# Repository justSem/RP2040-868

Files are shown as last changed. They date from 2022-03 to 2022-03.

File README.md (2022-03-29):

> `BE AWARE` This project is still in active development, I'm still in the process of ordering and testing prototypes, so the latest version is not tested to be fully-working as of yet.

# RP2040-868
A GPRS/GNSS/BTLE and LiPo/Li-ion charger integrated Pi Pico on credit-card format.

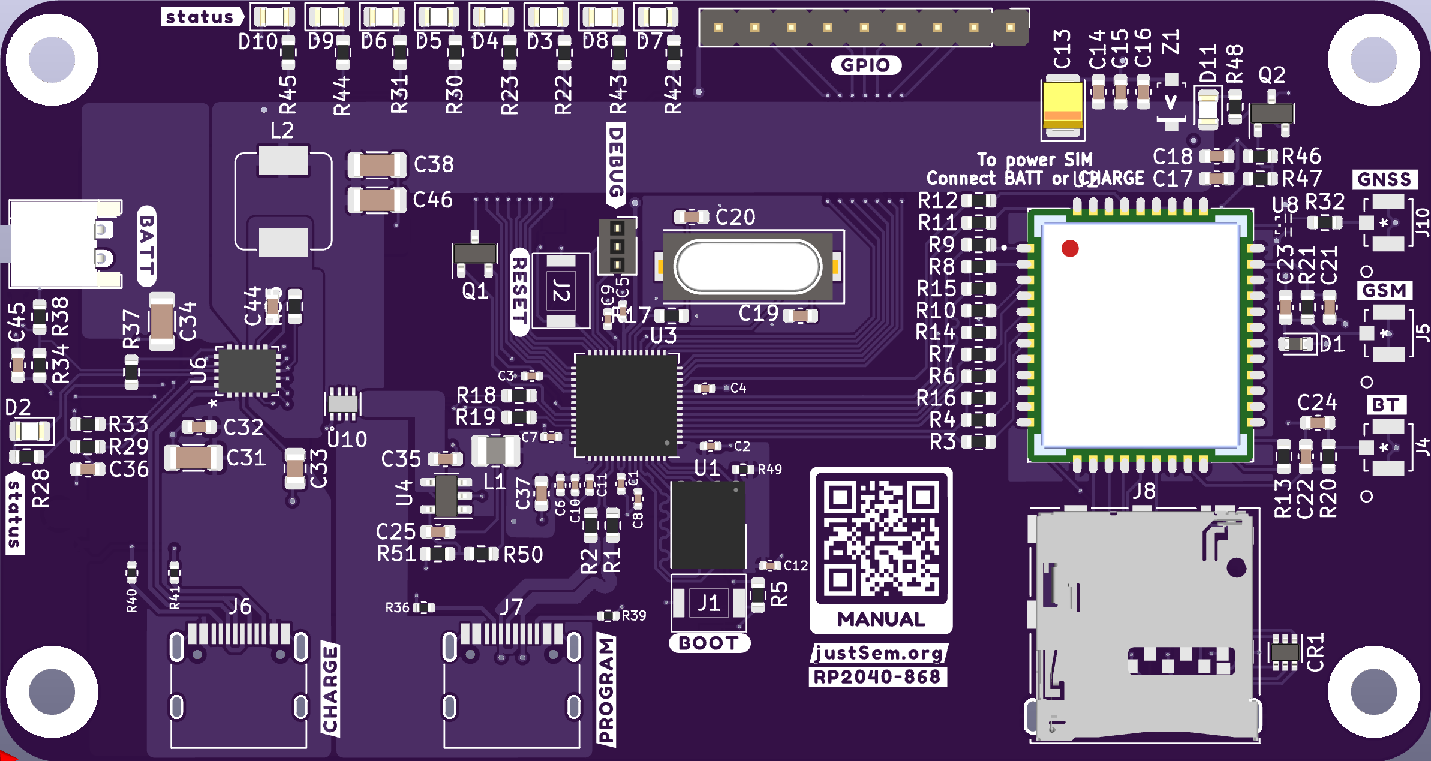
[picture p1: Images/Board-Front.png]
Board Front

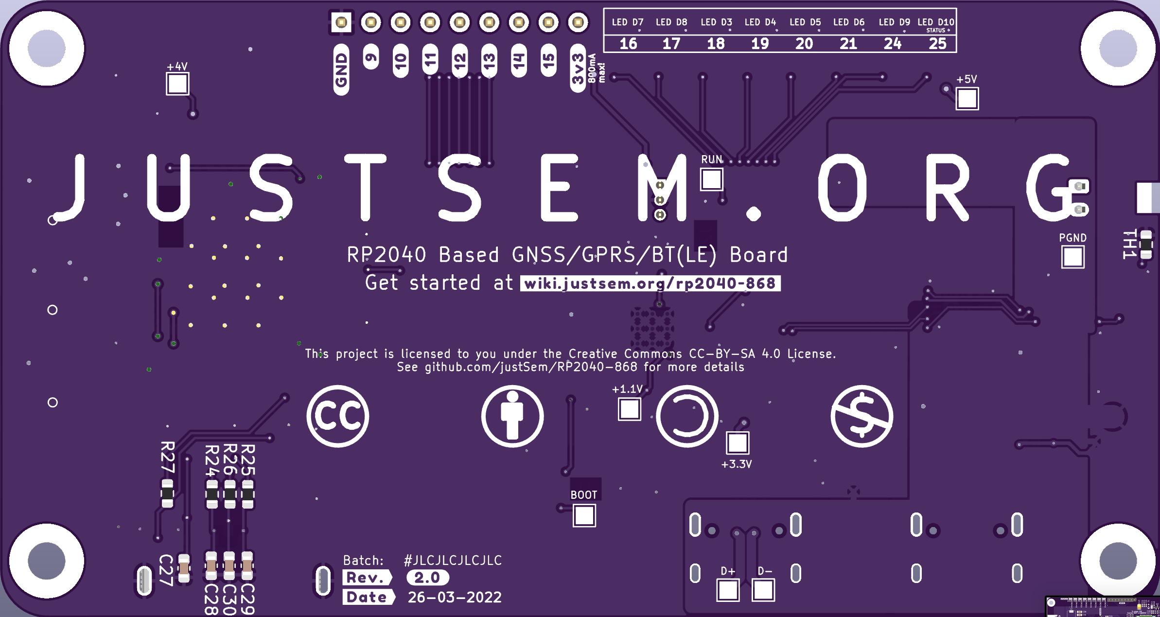
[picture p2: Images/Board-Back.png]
Board Rear

_Size: 99x50mm_

Title says it all!

This is a fully integrated RP2040-based board featuring the following:

* GPRS Enabled (with microSIM card format)
* GNSS (GPS, GLONASS, BEIDOU)
* BT(LE)
* Integrated LiPo/Li-ion charging circuit.
* USB-C (in USB2.0 mode) ports for future proofing.
* Programmable as if it's a "normal" RPI Pico
* Auto-switching power source: In case you connect both the Battery/USB Power and the USB-Program port, the device will automatically switch it's power source to the "PROG" port.

## The boards origin
Me and my friends work with GPS trackers a lot, for various purposes. For a while we used cheap AliExpress trackers, but we felt they couldn't be fully trusted. They're dirt-cheap but in return, closed-source.
We had absolutely no guarantee that it won't secretly send our data back to China.
So I decided to make our own version.

What started as a simple board grew out to be a fully-programmable board.
Since most of our group favor Python over C++ (simply because we're more used to Python :) ) we went with an RP2040

## Board Details
* The charger is a Monolithic Power [MP2624](https://www.monolithicpower.com/en/mp2624.html) 
* The GPRS/GNSS/BT(LE) Module is a SIMCom [SIM868](https://datasheet.lcsc.com/lcsc/1811011410_SIMCom-Wireless-Solutions-SIM868_C89549.pdf)
* At the heart of the board you'll find a Raspberry Pi [RP2040](https://datasheets.raspberrypi.com/rp2040/rp2040-datasheet.pdf)

## Quick Start
If you have the board you can simply access the programming mode by going through the following steps:
1. Connect a USB-C cable to the port labeled `PROG`
2. Press and hold the `RESET` button
3. Pres and hold the `PROG` button
4. Release the `RESET` button
5. Release the `PROG` button

The device should now present itself as removable storage to your system, allowing you to upload/download files to/from it.
You can use the provided code for some working examples.

## Costs
I haven't exactly calculated the costs. But for the 5 prototypes I built I spent roughly 30 euro's/board.
This includes overhead as some components had a minimium buy of 100 pieces.
So the exact costs are most likely below the number mentioned above.

# Planned Future
The plan is to make some changes in the future, these changes could be:

__Move to another Cellular Chip__

The SimCom chips can have 2A peak currents, which require a pcb designed to accomodate said currents.

__Support for more modern cellular acces__

GPRS is soon to be EOL. But at the time of writing there are no subsitutes which are worth the price in this project.
3G chips are available, but those networks are to be turned off 03-2022 in this country, which makes them not suitable for this project.
LTE-M (or other IoT bands) are still only available to commercial customers, chips for these networks are readily available but sadly not usable in this country.

For now it's waiting to see if any decent substitute will become available in the upcoming months.

__Support NanoSIM__

While it's theoretically possible with Rev 1.1 of the board, it hasn't been tested as of yet.

# F.A.Q.

__Do you sell these boards?__

No. I have no commercial interest with this project, but I might have spares at times, which I might be willing to send as long as you cover the costs.
Feel free to reach out if you're interested.

__Can you implement feature X?__

You're free to implement any software feature yourself. The boards are programmable for a reason :)

The board files can be altered using KiCad, enabling you to make hardware changes as well.

__I found a flaw__

Great! Please open an [issue](/issues/new/choose) and describe what you found.

# DISCLAIMER
I am in no way a professional PCB designer - this design could be flawed without me being aware of it.
I make things as a hobby without any guarantee on functionality, compatibility or reliability.
As stated in the [License](LICENSE.md) this product comes without any guarantee.

# CHANGELOG
### Rev 3.1
* Reversed change in crystal due to availability issues.
* Swapped SOIC-8 Flash for WSON variant.
* Removed SIM from `PROG` power-stage - no suitable DC-DC converter available for a reasonable price to do 5V->4V @ 2A.
* In order to access the SIM868 whilst programming, it is now required to either connect a battery, or an USB-cable to the `CHARGE` power-stage.

### Rev 2.0
* Swapped 100nF caps for 0402 to get them closer to the MCU.
* Moved around power-stage parts for thermal performance.
* Re-implemented USB connections to comply with USB Spec (impedance issues).

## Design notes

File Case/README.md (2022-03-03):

# RP2040-868 Case

__Revision:__ 1.0-TESTING

__CAUTION__: This is a _testing_ release. The case itself is still underway from the manufacturer - but it __should__ fit.

This 3d-printable case perfectly fits your board, and is additionally capable of holding a Triple-18650 Battery Pack. - I used [this](https://www.adafruit.com/product/5035) one as an example.

## On assembly

The screwholes on the side are made for standard M3 screws.
The holding pins in the bottom of the case are meant to hold M3 threaded inserts.

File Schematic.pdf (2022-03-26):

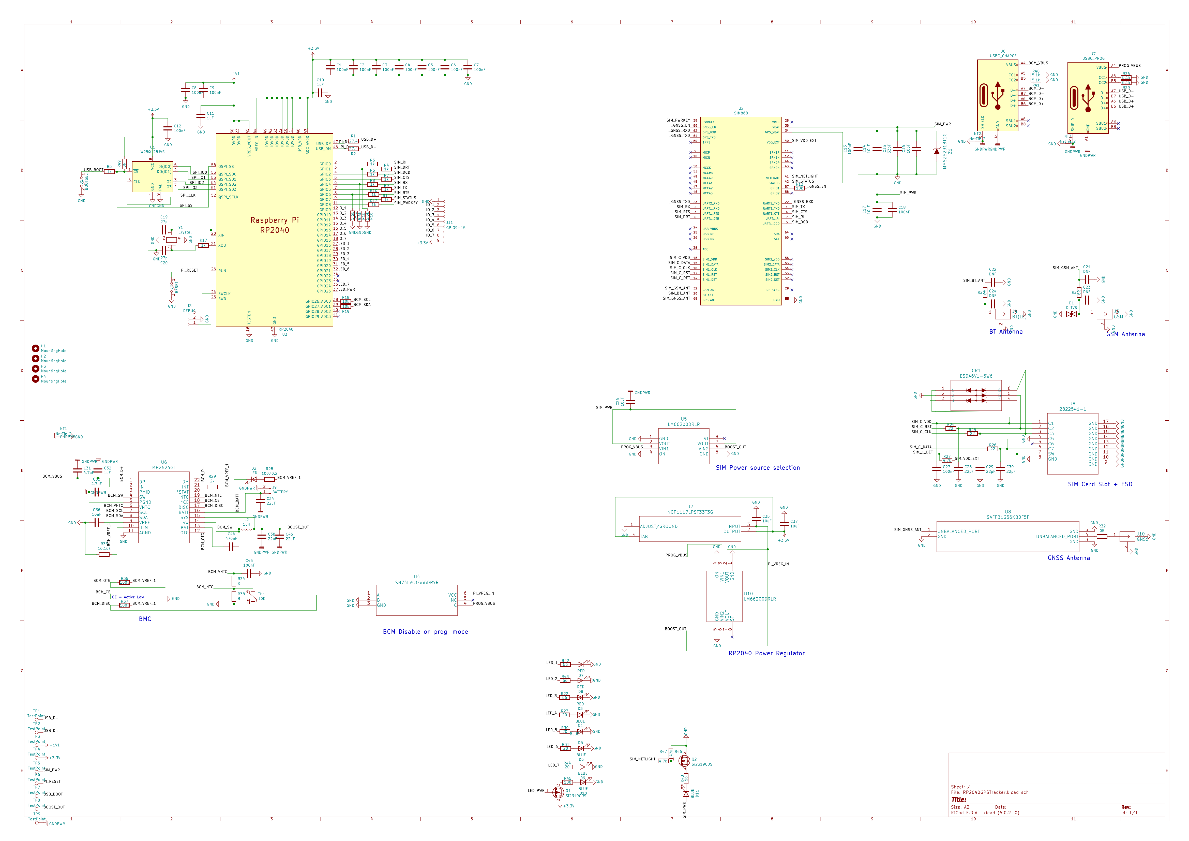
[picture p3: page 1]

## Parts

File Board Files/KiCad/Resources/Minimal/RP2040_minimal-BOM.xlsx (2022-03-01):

RP2040_minimal_r1 BOM
Item | Quantity | Reference | Part | Voltage | Current | Power | Material | Size | Tolerance | Manufacturer | Manuf. Part # | Description | Notes
1 | 3 | C1,C4,C17 | 10u | 16V |  |  | X5R | 0805_2012Metric | 10% | Murata | GRM21BR61C106KE15K | CAP CER 10UF 16V X5R 0805 | Or equivalent
2 | 2 | C2, C3 | 27p | 50V |  |  | C0G | 0402_1005Metric | 5% | Murata | GCM1555C1H270JA16D | CAP CER 27PF 50V C0G/NP0 0402 | Or equivalent
3 | 10 | C5, C6, C7, C9, C11, C12, C13, C14, C15, C16 | 100n | 25V |  |  | X7R | 0402_1005Metric | 10% | Murata | GRM155R71E104KE14J | CAP CER 0.1UF 25V X7R 0402 | Or equivalent
4 | 2 | C8, C10 | 1u | 10V |  |  | X6S | 0402_1005Metric | 10% | Murata | GRM155C81A105KA12D | CAP CER 1UF 10V X6S 0402 | Or equivalent
5 | 1 | J1 | USB_B_Micro |  |  |  |  |  |  | Amphenol | 10103594-0001LF | CONN RCPT USB2.0 MICRO B SMD R/A | Or equivalent
6 | 1 | J2 | 1x2 way header |  |  |  |  |  |  | Samtec | TSW-102-23-T-S | 2.54mm pin header 1x2 | Or equivalent
7 | 2 | J3, J4 | 2x18 way header |  |  |  |  |  |  | Samtec | TSW-118-23-T-D | 2.54mm pin header 2x18 | Or equivalent
8 | 2 | R1, R5 | 1k |  |  | 63mW |  | 0402_1005Metric | 1% | Yageo | RC0402FR-071KP | RES SMD 1K OHM 1% 1/16W 0402 | Or equivalent
9 | 1 | R2 | DNF |  |  |  |  | 0402_1005Metric |  |  |  |  | Do Not Fit
10 | 2 | R3, R4 | 27.4 |  |  | 63mW |  | 0402_1005Metric | 1% | Yageo | RC0402FR-0727R4L | RES SMD 27.4 OHM 1% 1/16W 0402 | Or equivalent
11 | 1 | U1 | NCP1117-3.3 |  |  |  |  | SOT-223-3 |  | ON Semiconductor | NCP1117ST33T3G | IC REG LINEAR 3.3V 1A SOT223
12 | 1 | U2 | W25Q128JVS |  |  |  |  | SOIC-8 |  | Winbond | W25Q128JVSIQ TR | IC FLASH 128M SPI 133MHZ 8SOIC
13 | 1 | U3 | RP2040 |  |  |  |  | QFN56 |  | Raspberry Pi | RP2040
14 | 1 | Y1 | ABLS-12.000MHZ-B4-T |  |  |  |  | HC49-US |  | Abracon | ABLS-12.000MHZ-B4-T | CRYSTAL 12.0000MHZ 18PF SMD

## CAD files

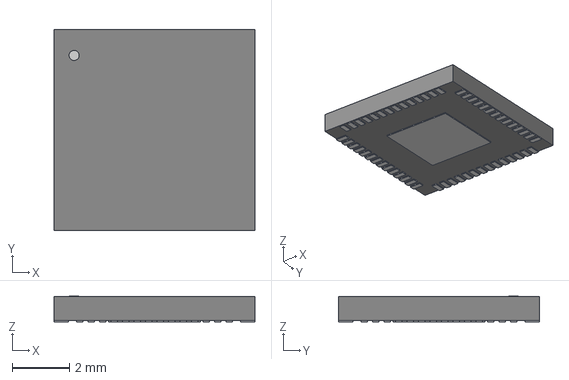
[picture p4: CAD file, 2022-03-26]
Board Files/KiCad/Resources/Minimal/QFN56_7X7_RPI.step
7.01 x 7.01 x 0.892 mm

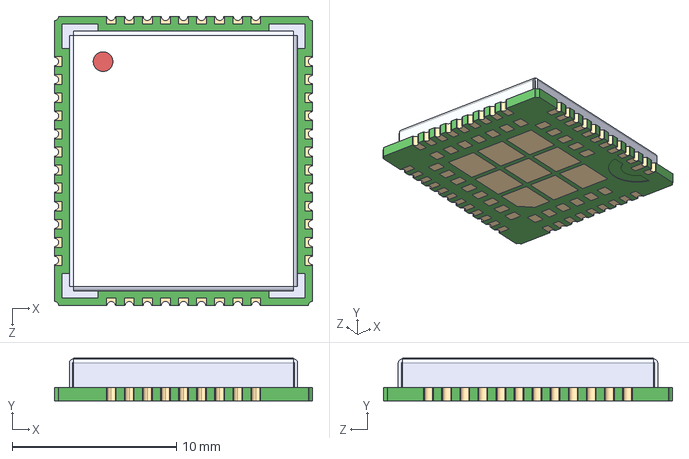
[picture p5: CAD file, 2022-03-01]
Board Files/KiCad/Resources/SIM868/SIM868.step
15.7 x 2.60 x 17.6 mm

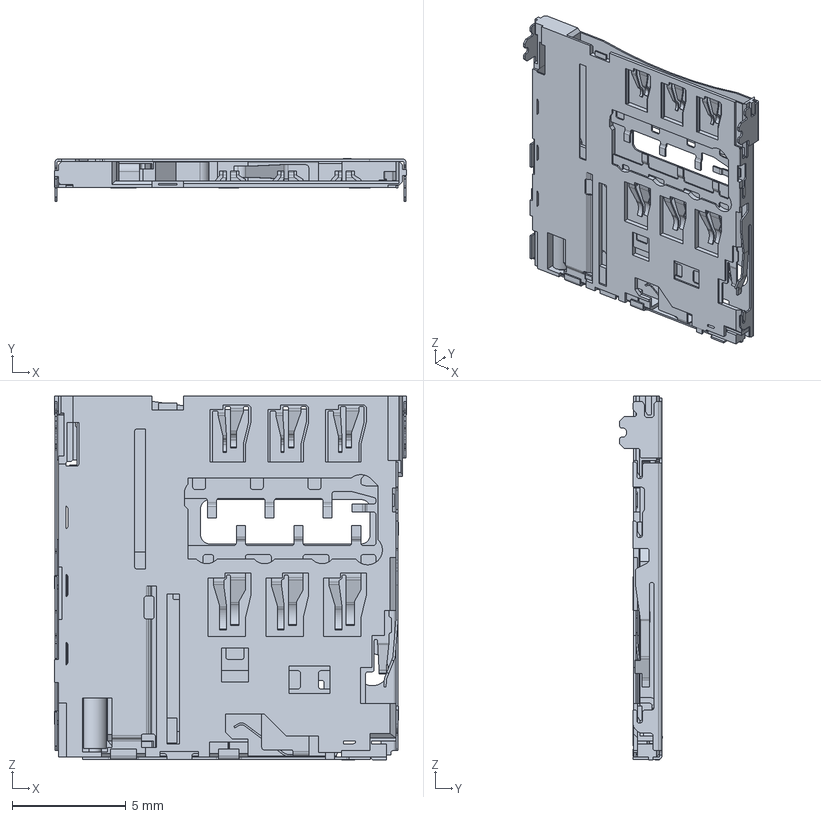
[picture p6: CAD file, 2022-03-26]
Board Files/KiCad/Resources/ul_2822541-1/c-2822541-1-c-3d.stp
15.5 x 1.89 x 16.0 mm

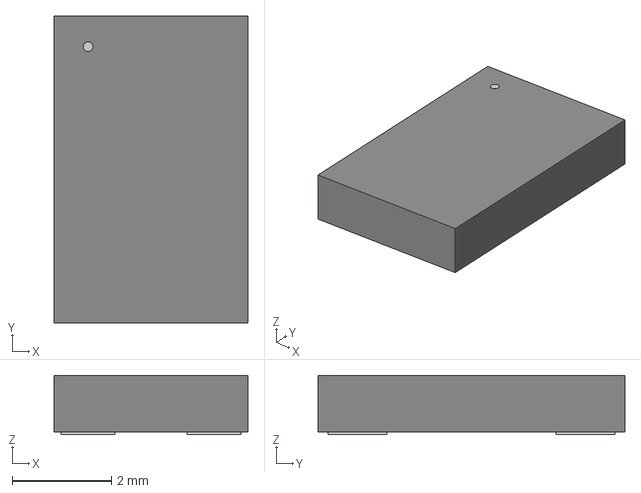
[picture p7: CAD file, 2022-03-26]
Board Files/KiCad/Resources/ul_ABMM2-12-000MHZ-E2-T/CRYSTAL_ABMM2_ABR.step
3.91 x 6.20 x 1.20 mm

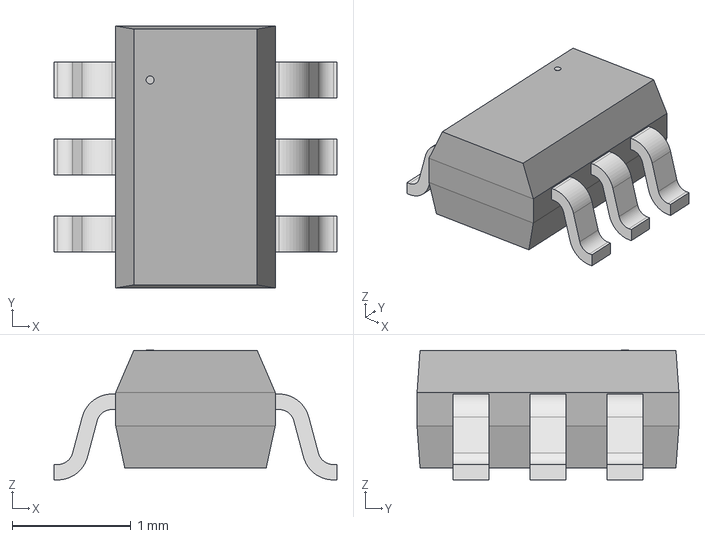
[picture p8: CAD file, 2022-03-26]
Board Files/KiCad/Resources/ul_ESDA6V1-5W6/STEP/SOT323-6L_STM.step
2.39 x 2.21 x 1.09 mm

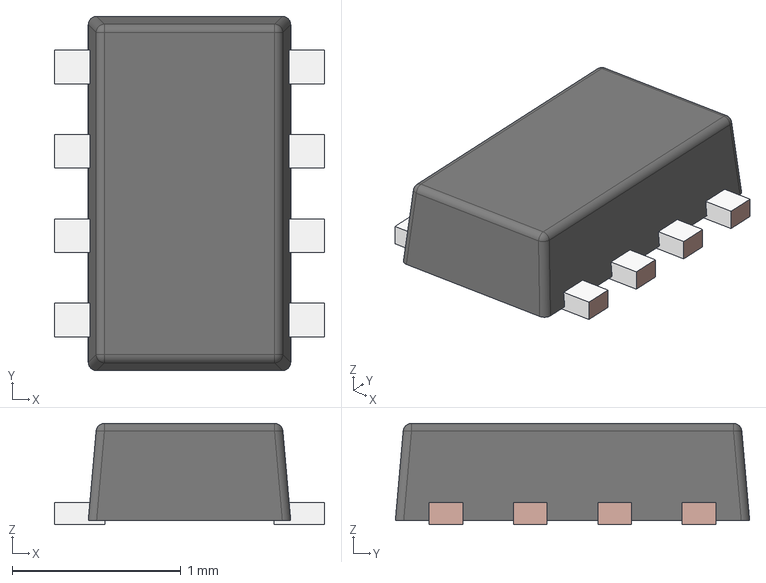
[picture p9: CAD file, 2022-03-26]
Board Files/KiCad/Resources/ul_LM66200DRLR/STEP/DRL0008A.stp
1.60 x 2.10 x 0.6 mm
FRAME-DRL0008A
BODY-SOT

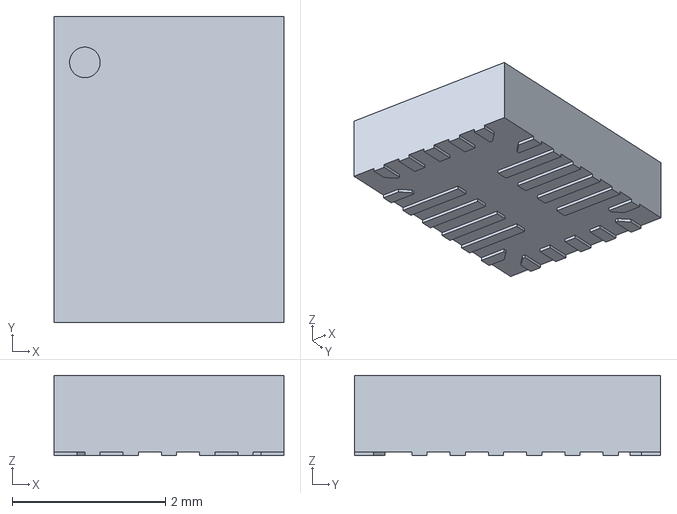
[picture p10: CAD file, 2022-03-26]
Board Files/KiCad/Resources/ul_MP2624GL/FreeCad.step
3.00 x 4.00 x 1.05 mm

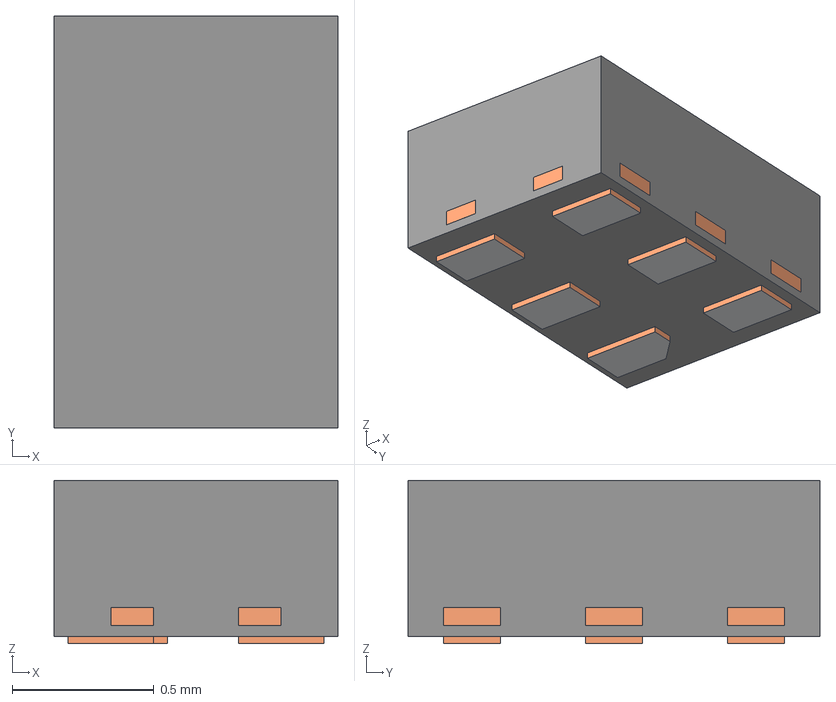
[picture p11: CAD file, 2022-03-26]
Board Files/KiCad/Resources/ul_SN74LVC1G66DRYR/DRY0006A.stp
1.00 x 1.45 x 0.575 mm
BODY-SON
FRAME-DRY0006A
PIN1-ID

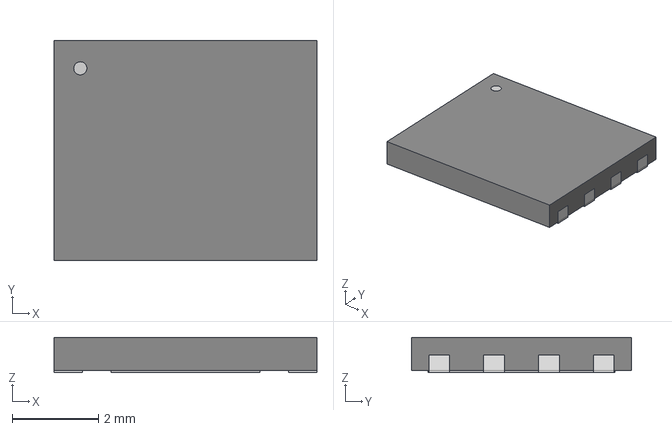
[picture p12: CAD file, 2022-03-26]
Board Files/KiCad/Resources/Winbond_Flash/WSON-8_6X5_WIN.step
6.10 x 5.11 x 0.815 mm

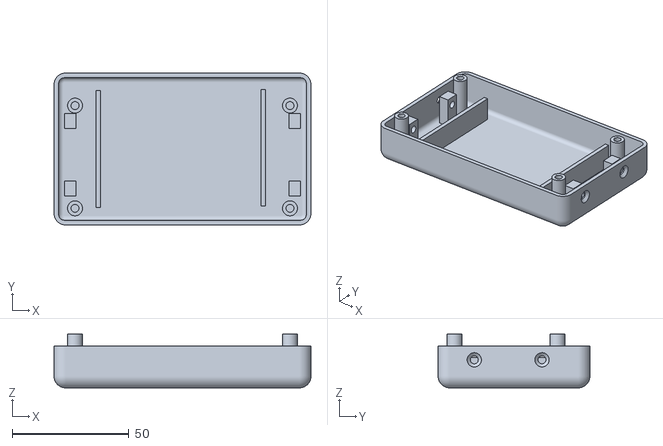
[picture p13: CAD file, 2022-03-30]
Case/Bottom-compat.stl
110.0 x 65.0 x 23.0

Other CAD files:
Case/Bottom.step

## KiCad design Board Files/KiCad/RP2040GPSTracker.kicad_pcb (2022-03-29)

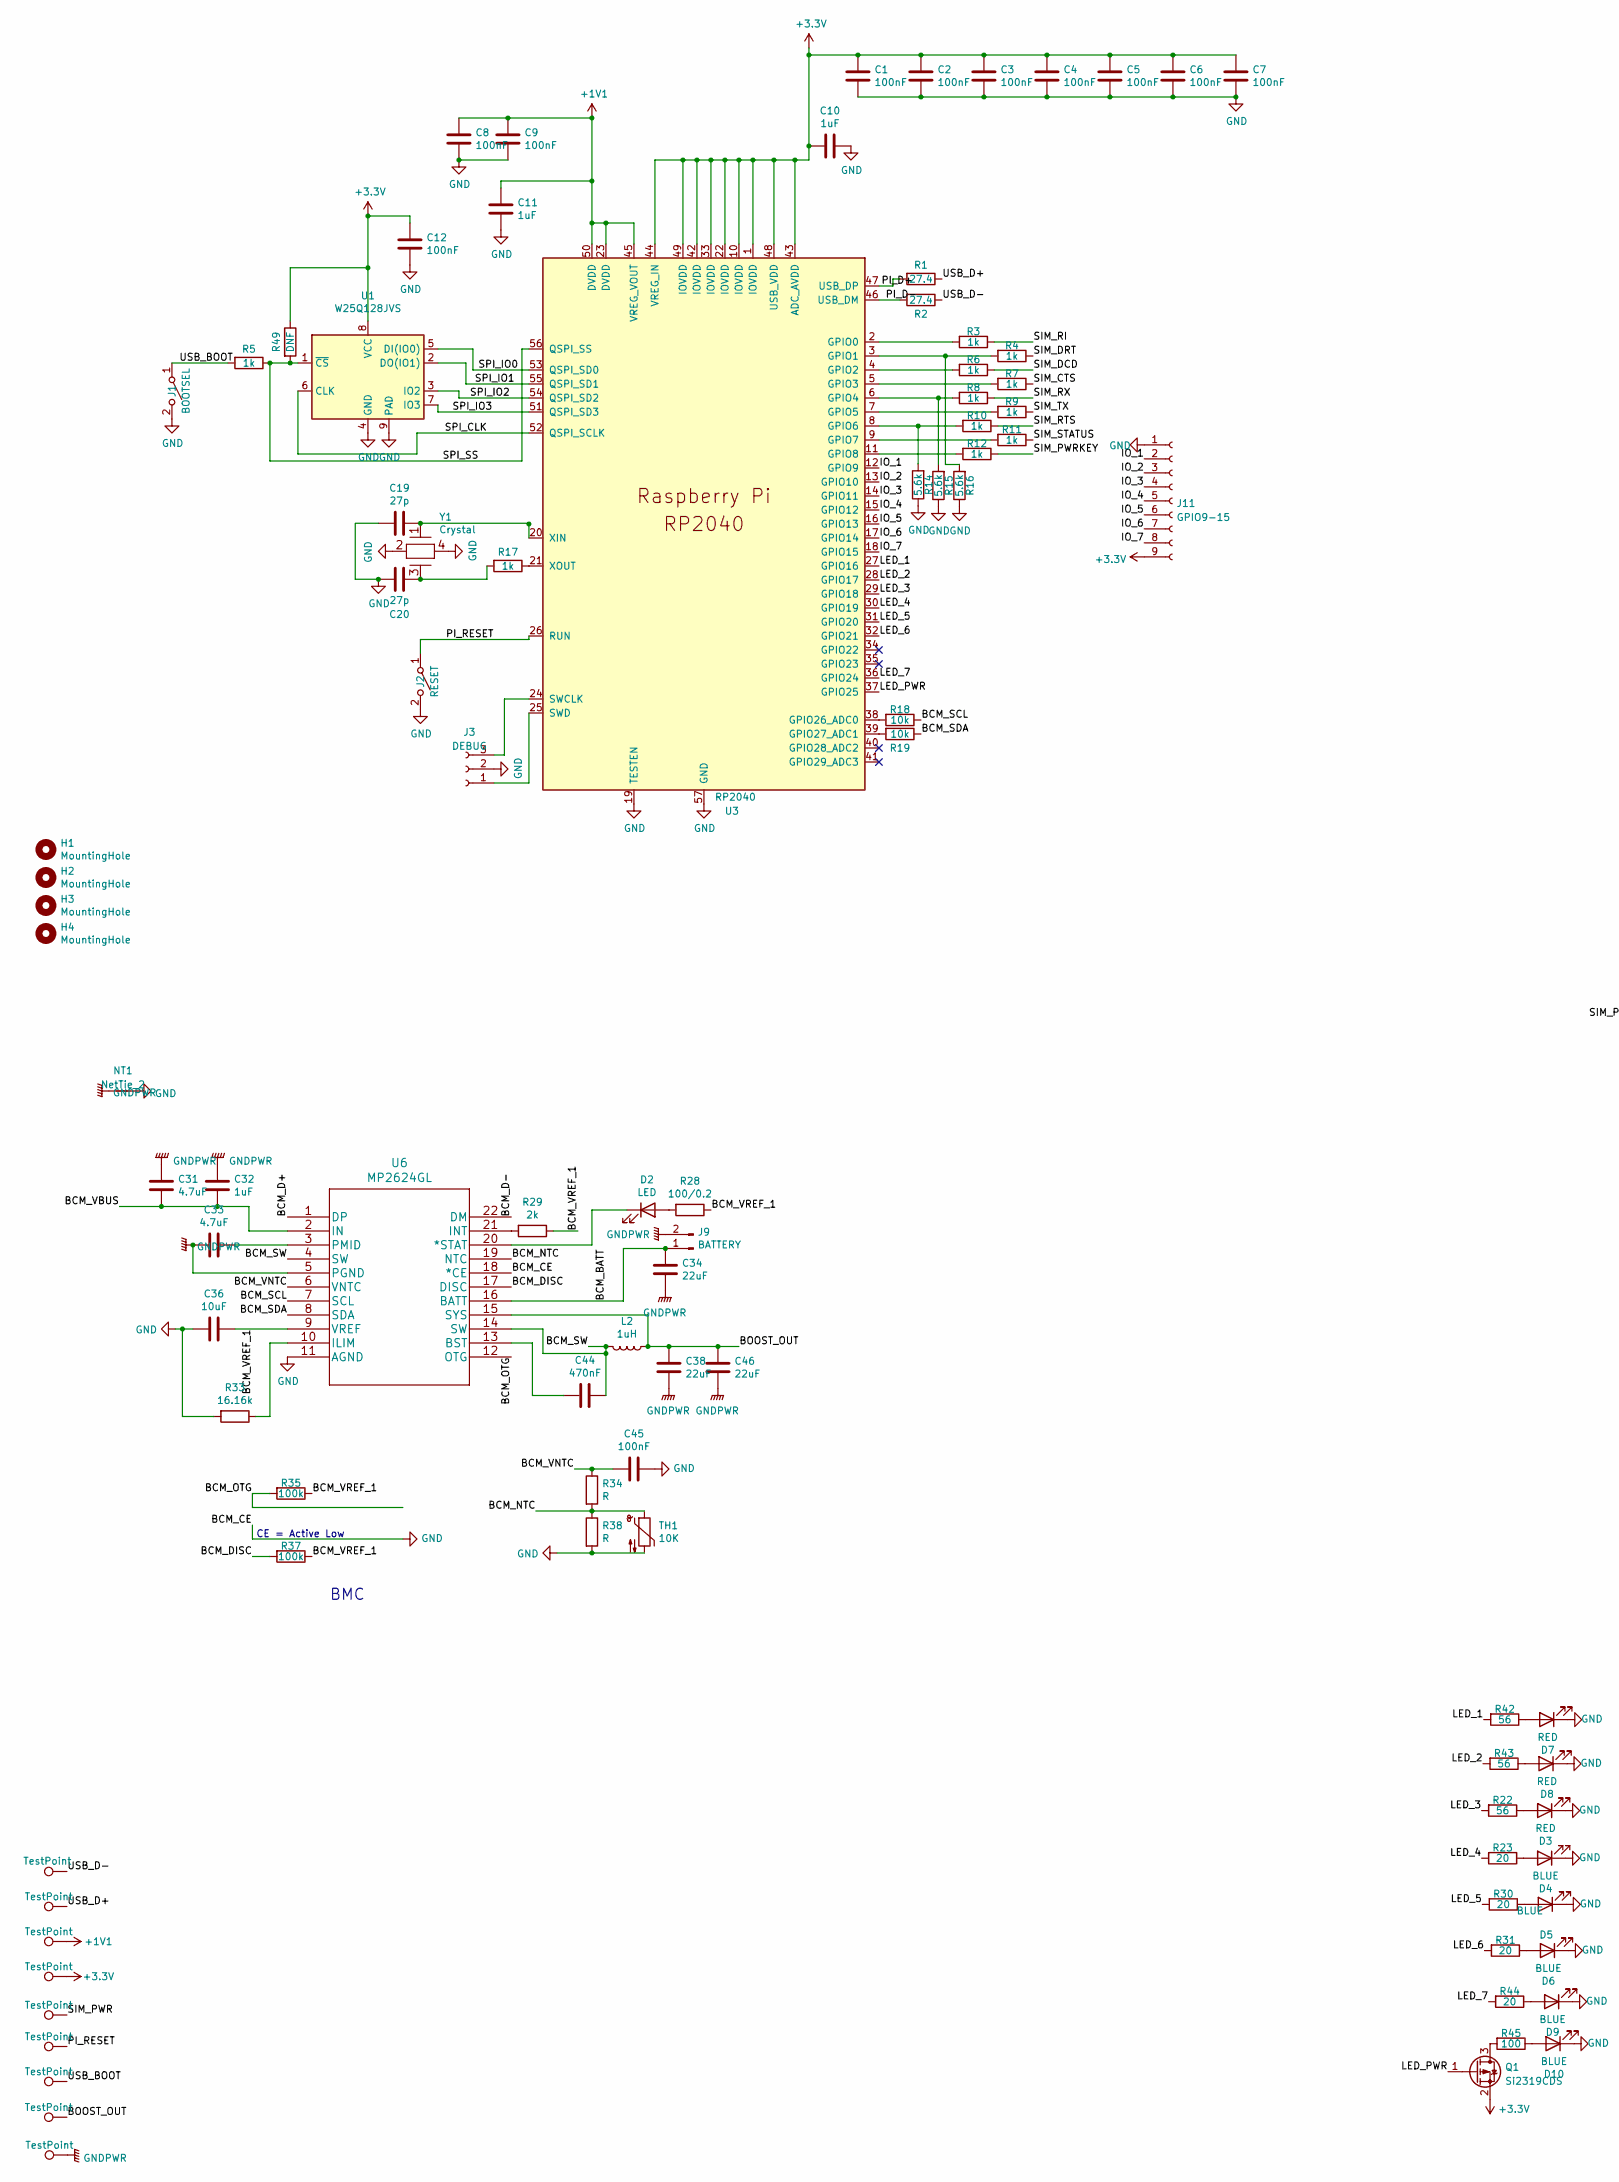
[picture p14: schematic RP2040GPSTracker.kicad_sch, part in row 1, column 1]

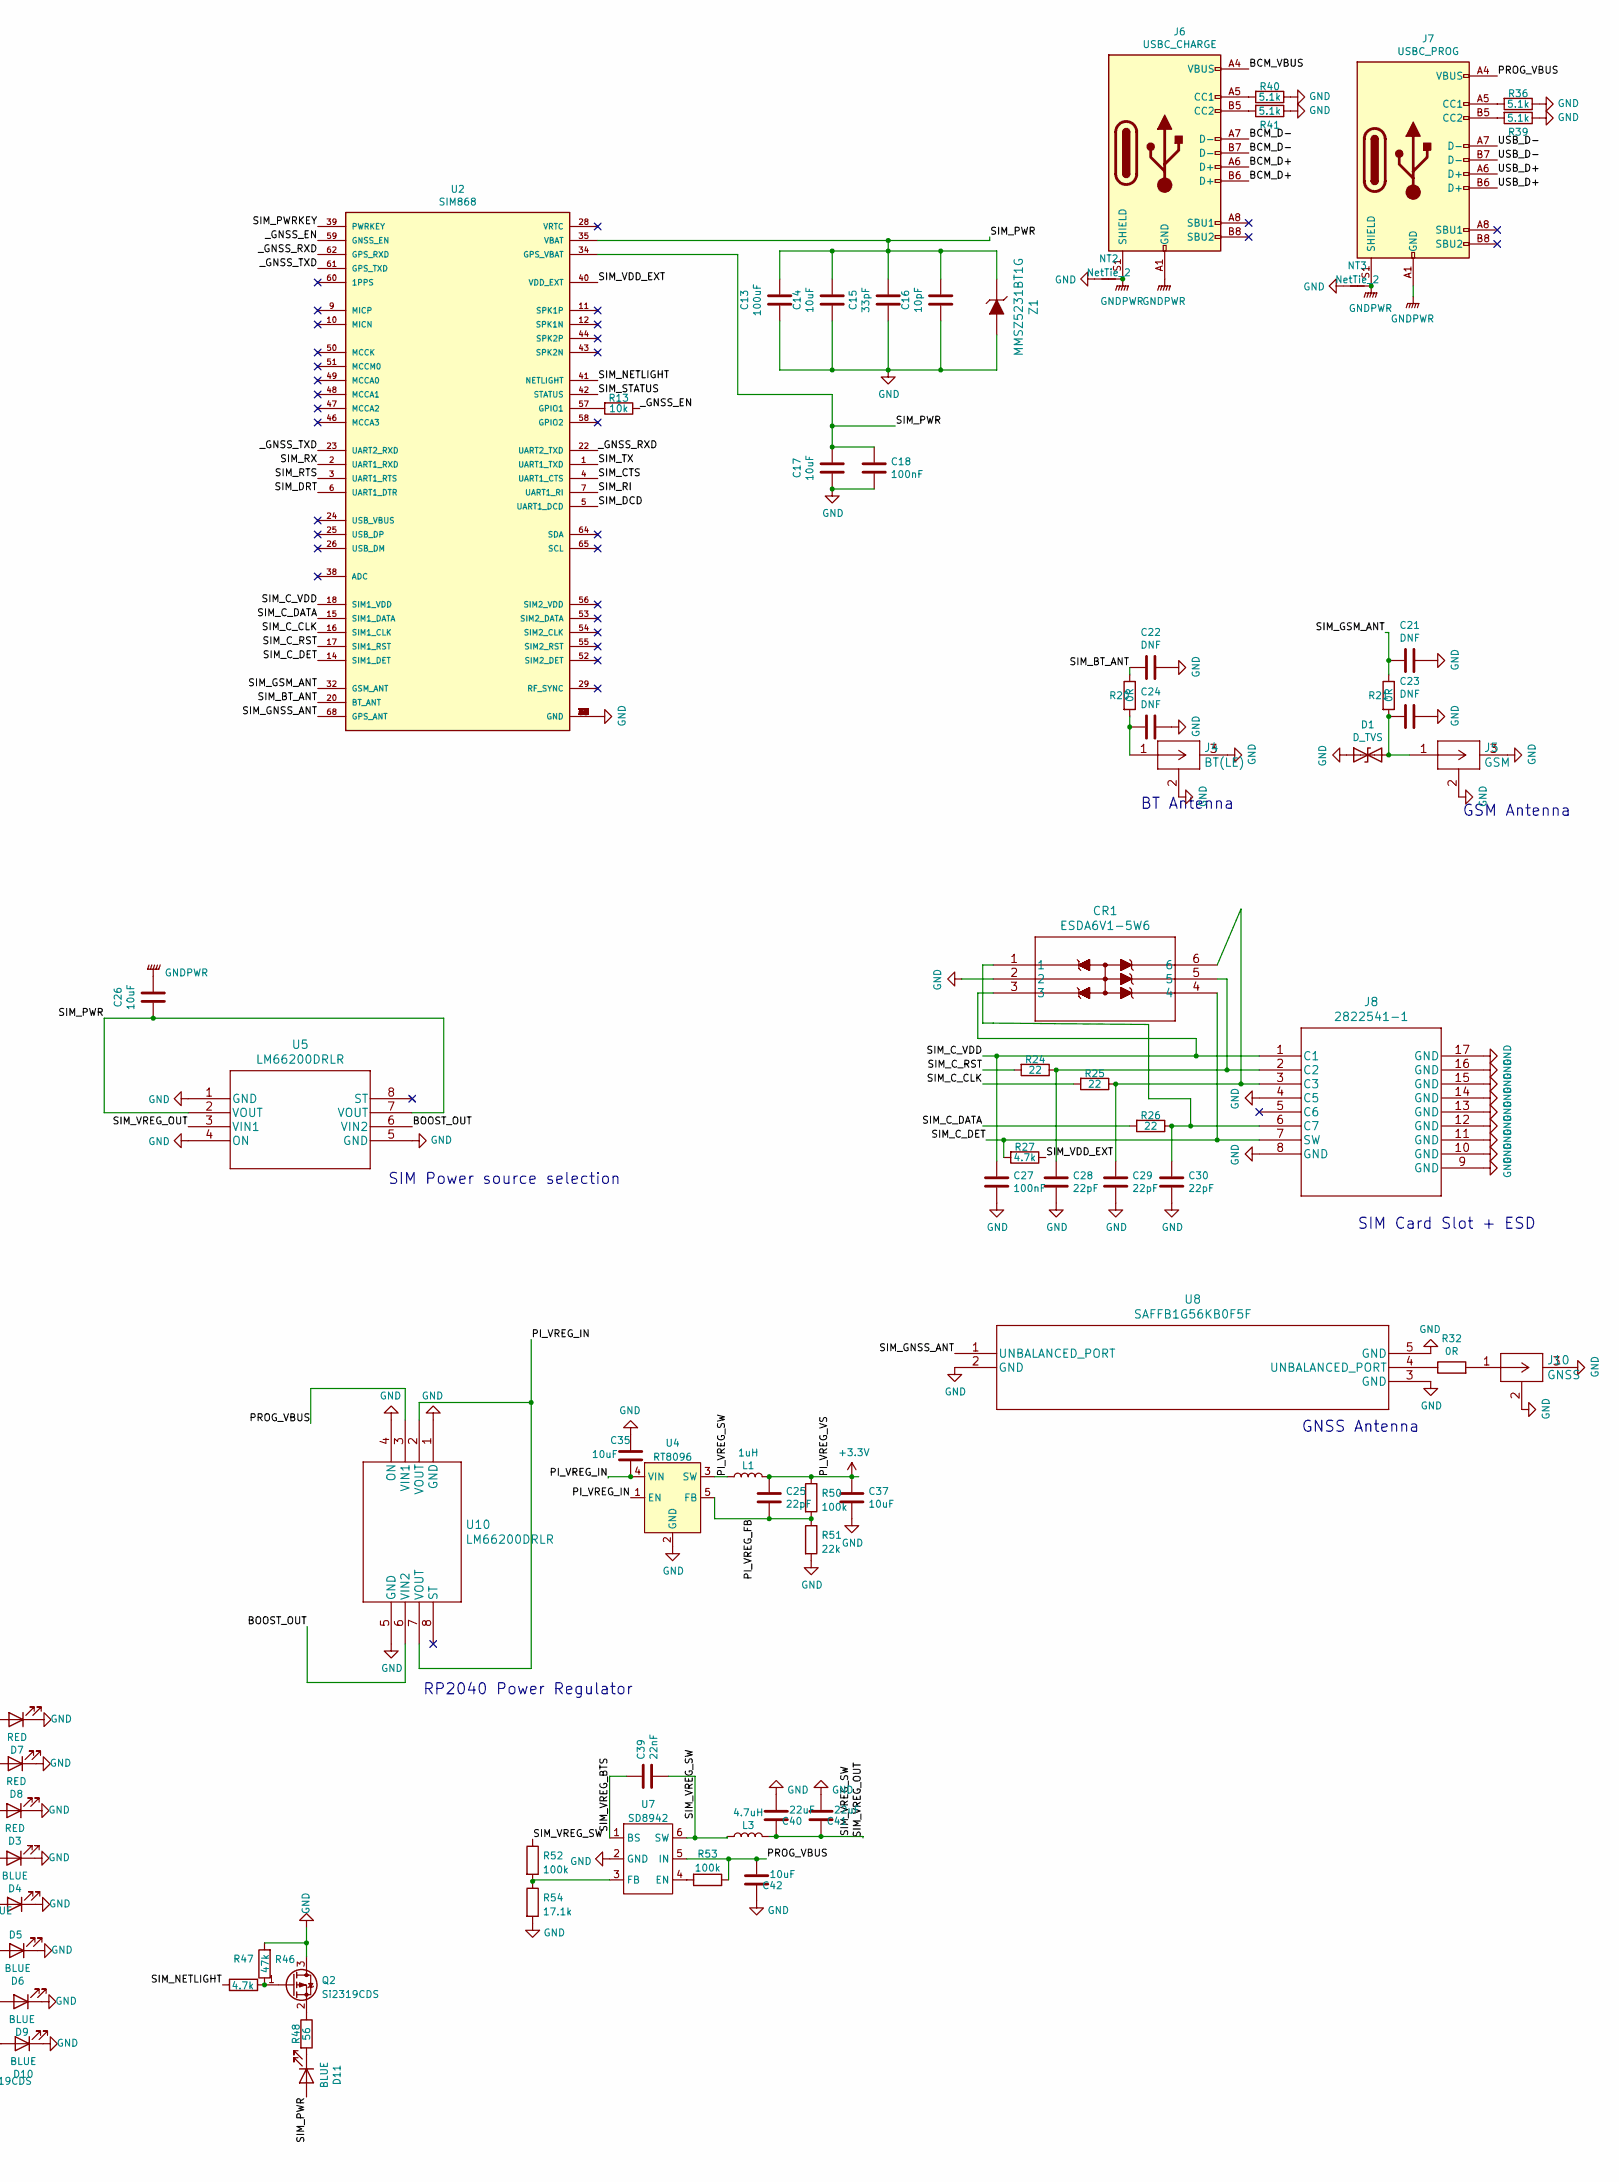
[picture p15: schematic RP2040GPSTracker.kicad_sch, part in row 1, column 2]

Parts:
C1, C2, C3, C4, C5, C6, C7, C8, C9, C12: 100nF; C_0402_1005Metric
C10, C11: 1uF; C_0402_1005Metric
C13: 100uF; CP_EIA-3528-15_AVX-H
C14, C17, C26, C35, C36, C37, C42: 10uF; C_0603_1608Metric
C15: 33pF; C_0603_1608Metric
C16: 10pF; C_0603_1608Metric
C18, C27, C45: 100nF; C_0603_1608Metric
C19, C20: 27p; C_0603_1608Metric
C21, C22, C23, C24: DNF; C_0603_1608Metric
C25, C28, C29, C30: 22pF; C_0603_1608Metric
C31: 4.7uF; C_1206_3216Metric
C32: 1uF; C_0603_1608Metric
C33: 4.7uF; C_0805_2012Metric
C34, C38, C46: 22uF; C_1206_3216Metric
C39: 22nF; C_0603_1608Metric
C40, C41: 22uF; C_0603_1608Metric
C44: 470nF; C_0603_1608Metric
CR1: ESDA6V1-5W6; SOT-363_SC-70-6
D1: D_TVS; D_0603_1608Metric
D2: LED; LED_0805_2012Metric
D3, D7, D8: RED; LED_0805_2012Metric
D4, D5, D6, D9, D10, D11: BLUE; LED_0805_2012Metric
H1, H2, H3, H4: MountingHole; MountingHole_3.2mm_M3_Pad
J1: BOOTSEL; SW_SPST_ALPS_SKRKAEE020
J2: RESET; SW_SPST_ALPS_SKRKAEE020
J3: DEBUG; PinSocket_1x03_P1.27mm_Vertical
J4: BT(LE); U.FL-R-SMT10
J5: GSM; U.FL-R-SMT10
J6: USBC_CHARGE; USB_C_Receptacle_HRO_TYPE-C-31-M-31
J7: USBC_PROG; USB_C_Receptacle_HRO_TYPE-C-31-M-31
J8: 2822541-1
J9: BATTERY; JST_PH_S2B-PH-K_1x02_P2.00mm_Horizontal
J10: GNSS; U.FL-R-SMT10
J11: GPIO9-15; PinHeader_1x09_P2.54mm_Vertical
L1: 1uH; L_1008_2520Metric
L2: 1uH; L_Sumida_CDMC6D28_7.25x6.5mm
L3: 4.7uH; MCS-0530
NT1: NetTie_2; NetTie-2_SMD_Pad2.0mm
NT2, NT3: NetTie_2; NetTie-2_SMD_Pad0.5mm
Q1, Q2: Si2319CDS; SOT-23
R1, R2: 27.4; R_0603_1608Metric
R3, R4, R5, R6, R7, R8, R9, R10, R11, R12, R17: 1k; R_0603_1608Metric
R13, R18, R19: 10k; R_0603_1608Metric
R14, R15, R16: 5.6k; R_0603_1608Metric
R20, R21, R32: 0R; R_0603_1608Metric
R22, R42, R43, R48: 56; R_0603_1608Metric
R23, R30, R31, R44: 20; R_0603_1608Metric
R24, R25, R26: 22; R_0603_1608Metric
R27, R47: 4.7k; R_0603_1608Metric
R28: 100/0.2; R_0603_1608Metric
R29: 2k; R_0603_1608Metric
R33: 16.16k; R_0603_1608Metric
R34, R38: R; R_0603_1608Metric
R35, R37, R50, R52, R53: 100k; R_0603_1608Metric
R36, R39, R40, R41: 5.1k; R_0402_1005Metric
R45: 100; R_0603_1608Metric
R46: 47k; R_0603_1608Metric
R49: DNF; R_0402_1005Metric
R51: 22k; R_0603_1608Metric
R54: 17.1k; R_0603_1608Metric
TH1: 10K; R_0603_1608Metric
TP1, TP2, TP3, TP4, TP5, TP6, TP7, TP8, TP9: TestPoint; TestPoint_Pad_1.5x1.5mm
U1: W25Q128JVS; WSON-8-1EP_6x5mm_P1.27mm_EP3.4x4.3mm
U2: SIM868; XCVR_SIM868
U3: RP2040; RP2040-QFN-56
U4: RT8096; TSOT-23-5
U5, U10: LM66200DRLR
U6: MP2624GL
U7: SD8942; SOT-23-6
U8: SAFFB1G56KB0F5F
Y1: Crystal; ABMM2-12.000MHZ-E2-T
Z1: MMSZ5231BT1G; SOD-123; MPN MMSZ5231BT1G; Digi-Key_PN MMSZ5231B-FDICT-ND

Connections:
+1V1: C8.1, C9.1, C11.1, TP3.1, U3.23 (DVDD), U3.45 (VREG_VOUT), U3.50 (DVDD)
+3V3: C1.2, C2.2, C3.2, C4.2, C5.2, C6.2, C7.2, C10.2, C12.1, C25.1, C37.1, J11.9, L1.2, Q1.2 (S), R49.1, R50.1, TP4.1, U1.8 (VCC), U3.1 (IOVDD), U3.10 (IOVDD), U3.22 (IOVDD), U3.33 (IOVDD), U3.42 (IOVDD), U3.43 (ADC_AVDD), U3.44 (VREG_IN), U3.48 (USB_VDD), U3.49 (IOVDD)
/BCM_BATT: C34.1, J9.1, U6.16 (BATT)
/BCM_D+: J6.A6 (D+), J6.B6 (D+), U6.1 (DP)
/BCM_D-: J6.A7 (D-), J6.B7 (D-), U6.22 (DM)
/BCM_DISC: R37.2, U6.17 (DISC)
/BCM_NTC: R34.2, R38.1, TH1.1, U6.19 (NTC)
/BCM_OTG: R35.2, U6.12 (OTG)
/BCM_SCL: R18.1, U6.7 (SCL)
/BCM_SDA: R19.1, U6.8 (SDA)
/BCM_SW: C44.1, L2.2, U6.4 (SW), U6.14 (SW)
/BCM_VBUS: C31.2, C32.2, J6.A4 (VBUS), J6.A9 (VBUS), J6.B4 (VBUS), J6.B9 (VBUS), U6.2 (IN)
/BCM_VNTC: C45.1, R34.1, U6.6 (VNTC)
/BCM_VREF_1: C36.1, R28.1, R29.1, R35.1, R37.1, U6.9 (VREF)
/IO_1: J11.2, U3.12 (GPIO9)
/IO_2: J11.3, U3.13 (GPIO10)
/IO_3: J11.4, U3.14 (GPIO11)
/IO_4: J11.5, U3.15 (GPIO12)
/IO_5: J11.6, U3.16 (GPIO13)
/IO_6: J11.7, U3.17 (GPIO14)
/IO_7: J11.8, U3.18 (GPIO15)
/LED_1: R42.2, U3.27 (GPIO16)
/LED_2: R43.2, U3.28 (GPIO17)
/LED_3: R22.2, U3.29 (GPIO18)
/LED_4: R23.2, U3.30 (GPIO19)
/LED_5: R30.2, U3.31 (GPIO20)
/LED_6: R31.2, U3.32 (GPIO21)
/LED_7: R44.2, U3.36 (GPIO24)
/LED_PWR: Q1.1 (G), U3.37 (GPIO25)
/PI_D+: R1.2, U3.47 (USB_DP)
/PI_D-: R2.2, U3.46 (USB_DM)
/PI_RESET: J2.1 (A), TP6.1, U3.26 (RUN)
/PI_VREG_FB: C25.2, R50.2, R51.1, U4.5 (FB)
/PI_VREG_IN: C35.2, U4.1 (EN), U4.4 (VIN), U10.2 (VOUT), U10.7 (VOUT)
/PI_VREG_SW: L1.1, U4.3 (SW)
/PROG_VBUS: C42.2, J7.A4 (VBUS), J7.A9 (VBUS), J7.B4 (VBUS), J7.B9 (VBUS), R53.1, U7.5 (IN), U10.3 (VIN1)
/SIM_BT_ANT: C22.2, R20.1, U2.20 (BT_ANT)
/SIM_CTS: R7.1, U2.4 (UART1_CTS)
/SIM_C_CLK: R25.2, U2.16 (SIM1_CLK)
/SIM_C_DATA: R26.2, U2.15 (SIM1_DATA)
/SIM_C_DET: CR1.4, J8.7 (SW), R27.2, U2.14 (SIM1_DET)
/SIM_C_RST: R24.2, U2.17 (SIM1_RST)
/SIM_C_VDD: C27.2, CR1.3, J8.1 (C1), U2.18 (SIM1_VDD)
/SIM_DCD: R6.1, U2.5 (UART1_DCD)
/SIM_DRT: R4.1, U2.6 (UART1_DTR)
/SIM_GNSS_ANT: U2.68 (GPS_ANT), U8.1 (UNBALANCED_PORT)
/SIM_GSM_ANT: C21.2, R21.1, U2.32 (GSM_ANT)
/SIM_NETLIGHT: R47.1, U2.41 (NETLIGHT)
/SIM_PWRKEY: R12.1, U2.39 (PWRKEY)
/SIM_RI: R3.1, U2.7 (UART1_RI)
/SIM_RTS: R10.1, U2.3 (UART1_RTS)
/SIM_RX: R8.1, U2.2 (UART1_RXD)
/SIM_STATUS: R11.1, U2.42 (STATUS)
/SIM_TX: R9.1, U2.1 (UART1_TXD)
/SIM_VDD_EXT: R27.1, U2.40 (VDD_EXT)
/SPI_CLK: U1.6 (CLK), U3.52 (QSPI_SCLK)
/SPI_IO0: U1.5 (DI(IO0)), U3.53 (QSPI_SD0)
/SPI_IO1: U1.2 (DO(IO1)), U3.55 (QSPI_SD1)
/SPI_IO2: U1.3 (IO2), U3.54 (QSPI_SD2)
/SPI_IO3: U1.7 (IO3), U3.51 (QSPI_SD3)
/SPI_SS: R5.1, R49.2, U1.1 (~CS), U3.56 (QSPI_SS)
/USB_BOOT: J1.1 (A), R5.2, TP7.1
/USB_D+: J7.A6 (D+), J7.B6 (D+), R1.1, TP2.1
/USB_D-: J7.A7 (D-), J7.B7 (D-), R2.1, TP1.1
/_GNSS_EN: R13.1, U2.59 (GNSS_EN)
/_GNSS_RXD: U2.22 (UART2_TXD), U2.62 (GPS_RXD)
/_GNSS_TXD: U2.23 (UART2_RXD), U2.61 (GPS_TXD)
GNDPWR: C26.1, C31.1, C32.1, C33.2, C34.2, C38.2, C46.2, J6.A1 (GND), J6.A12 (GND), J6.B1 (GND), J6.B12 (GND), J6.S1 (SHIELD), J7.A1 (GND), J7.A12 (GND), J7.B1 (GND), J7.B12 (GND), J7.S1 (SHIELD), J9.2, NT1.1, NT2.2, NT3.2, TP9.1, U6.5 (PGND)
unnamed: C19.1, U3.20 (XIN), Y1.1
unnamed: C23.2, D1.2 (A2), J5.1, R21.2
unnamed: C24.2, J4.1, R20.2
unnamed: C28.2, CR1.5, J8.2 (C2), R24.1
unnamed: C29.2, CR1.6, J8.3 (C3), R25.1
unnamed: C30.2, CR1.1, J8.6 (C7), R26.1
unnamed: C33.1, U6.3 (PMID)
unnamed: C39.1, U7.1 (BS)
unnamed: C39.2, C40.1, C41.1, L3.1, L3.2, R52.1, U5.3 (VIN1), U7.6 (SW)
unnamed: C44.2, U6.13 (BST)
unnamed: D2.1 (K), U6.20 (*STAT)
unnamed: D2.2 (A), R28.2
unnamed: D3.2 (A), R22.1
unnamed: D4.2 (A), R23.1
unnamed: D5.2 (A), R30.1
unnamed: D6.2 (A), R31.1
unnamed: D7.2 (A), R42.1
unnamed: D8.2 (A), R43.1
unnamed: D9.2 (A), R44.1
unnamed: D10.2 (A), R45.1
unnamed: D11.1 (K), R48.2
unnamed: J3.1, U3.25 (SWD)
unnamed: J3.3, U3.24 (SWCLK)
unnamed: J6.A5 (CC1), R40.2
unnamed: J6.B5 (CC2), R41.2
unnamed: J7.A5 (CC1), R36.2
unnamed: J7.B5 (CC2), R39.2
unnamed: J10.1, R32.2
unnamed: Q1.3 (D), R45.2
unnamed: Q2.1 (G), R46.1, R47.2
unnamed: Q2.2 (S), R48.1
unnamed: R3.2, U3.2 (GPIO0)
unnamed: R6.2, U3.4 (GPIO2)
unnamed: R7.2, U3.5 (GPIO3)
unnamed: R9.2, U3.7 (GPIO5)
unnamed: R10.2, R14.2, U3.8 (GPIO6)
unnamed: R11.2, U3.9 (GPIO7)
unnamed: R12.2, U3.11 (GPIO8)
unnamed: R13.2, U2.57 (GPIO1)
unnamed: R8.2, R15.2, U3.6 (GPIO4)
unnamed: R4.2, R16.2, U3.3 (GPIO1)
unnamed: R17.1, U3.21 (XOUT)
unnamed: R18.2, U3.38 (GPIO26_ADC0)
unnamed: R19.2, U3.39 (GPIO27_ADC1)
unnamed: R29.2, U6.21 (INT)
unnamed: R32.1, U8.4 (UNBALANCED_PORT)
unnamed: R33.1, U6.10 (ILIM)
unnamed: R52.2, R54.1, U7.3 (FB)
unnamed: R53.2, U7.4 (EN)

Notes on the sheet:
SIM Card Slot + ESD
RP2040 Power Regulator
SIM Power source selection
BMC
GNSS Antenna
BT Antenna
GSM Antenna
CE = Active Low

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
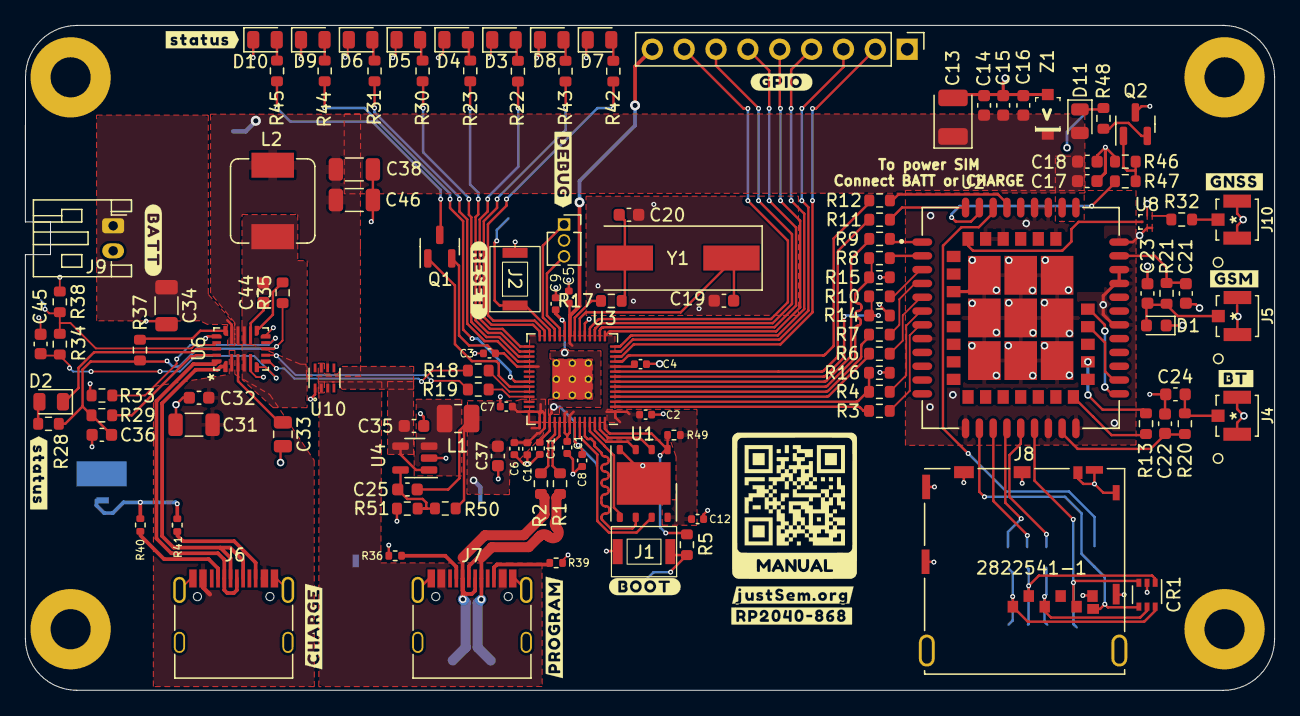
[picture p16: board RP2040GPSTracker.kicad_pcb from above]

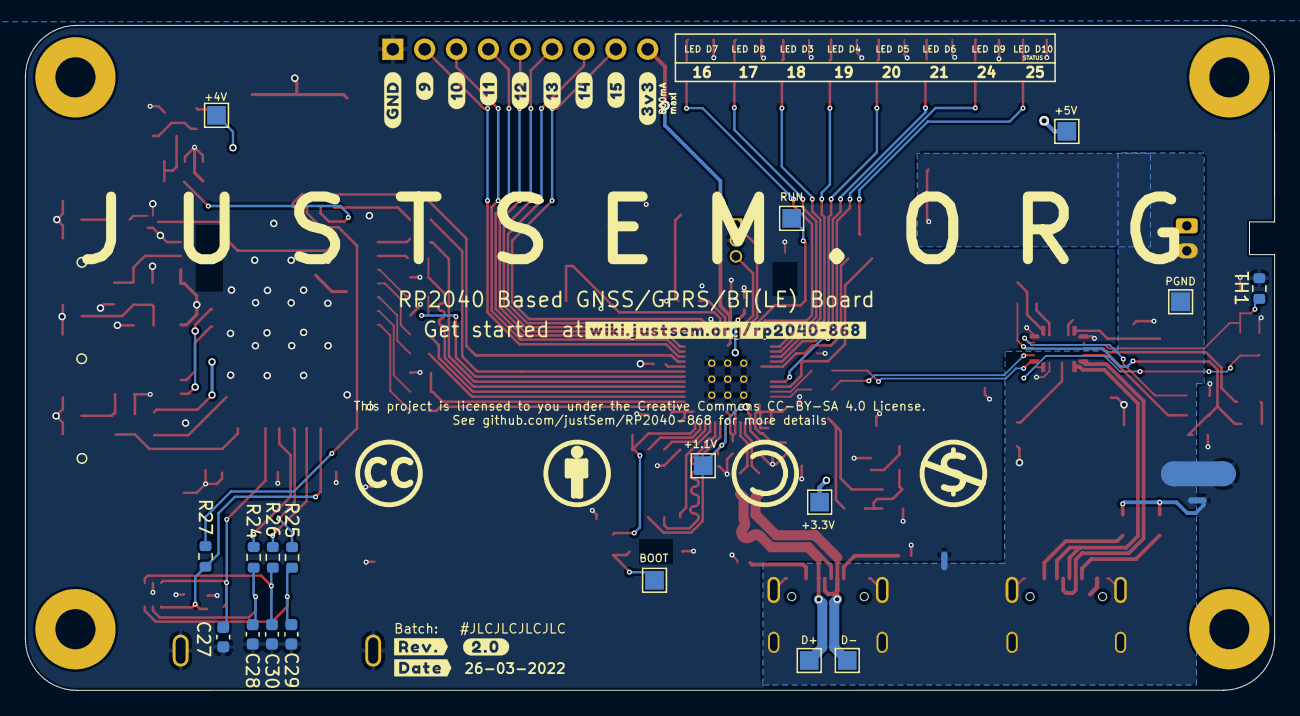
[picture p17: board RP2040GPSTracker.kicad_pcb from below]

Board: 2 copper layers, 99.6 x 53.0 mm, 144 parts (21 on the bottom side), 116 nets.

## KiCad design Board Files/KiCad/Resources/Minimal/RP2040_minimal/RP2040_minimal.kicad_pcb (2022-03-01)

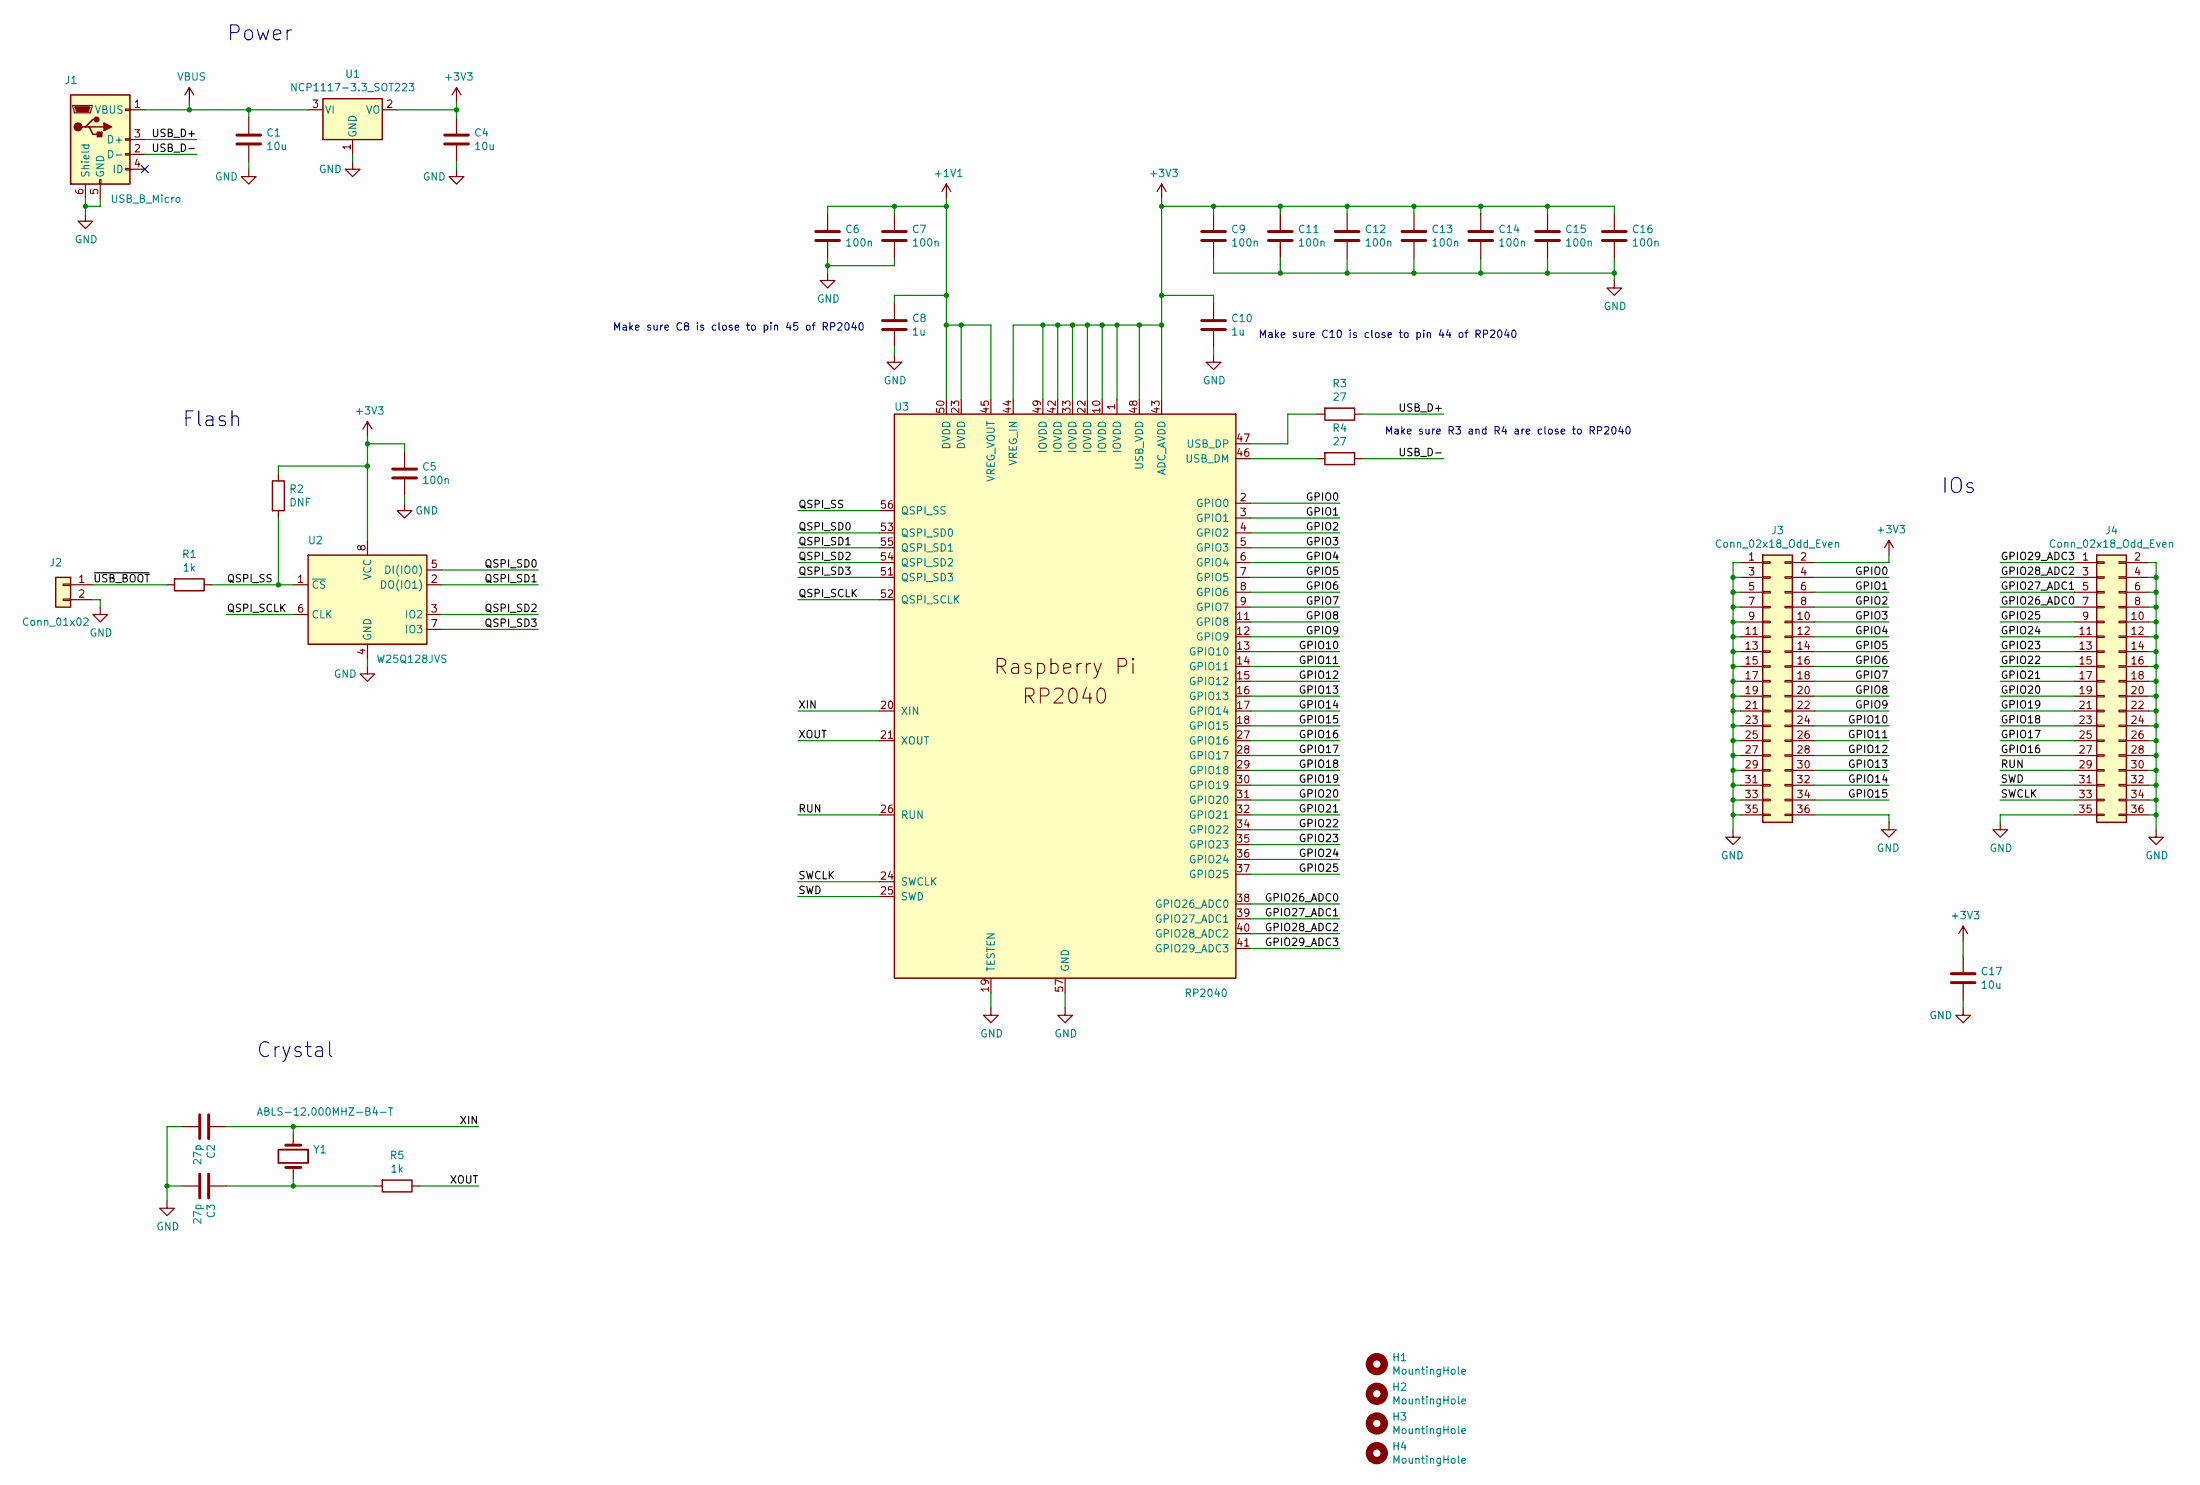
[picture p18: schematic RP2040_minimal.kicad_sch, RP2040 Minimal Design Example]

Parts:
C1, C4, C17: 10u; C_0805_2012Metric
C2, C3: 27p; C_0402_1005Metric
C5, C6, C7, C9, C11, C12, C13, C14, C15, C16: 100n; C_0402_1005Metric
C8, C10: 1u; C_0402_1005Metric
H1, H2, H3, H4: MountingHole; MountingHole_2.7mm_M2.5
J1: USB_B_Micro; USB_Micro-B_Amphenol_10103594-0001LF_Horizontal_modified
J2: Conn_01x02; PinHeader_1x02_P2.54mm_Vertical
J3, J4: Conn_02x18_Odd_Even; PinHeader_2x18_P2.54mm_Vertical
R1, R5: 1k; C_0402_1005Metric
R2: DNF; C_0402_1005Metric
R3, R4: 27; C_0402_1005Metric
U1: NCP1117-3.3_SOT223; SOT-223-3_TabPin2
U2: W25Q128JVS; SOIC-8_5.23x5.23mm_P1.27mm
U3: RP2040; RP2040-QFN-56
Y1: ABLS-12.000MHZ-B4-T; Crystal_SMD_HC49-US

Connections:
+1V1: C6.1, C7.1, C8.1, U3.23 (DVDD), U3.45 (VREG_VOUT), U3.50 (DVDD)
+3V3: C4.1, C5.1, C9.1, C10.1, C11.1, C12.1, C13.1, C14.1, C15.1, C16.1, C17.1, J3.2, R2.1, U1.2 (VO), U2.8 (VCC), U3.1 (IOVDD), U3.10 (IOVDD), U3.22 (IOVDD), U3.33 (IOVDD), U3.42 (IOVDD), U3.43 (ADC_AVDD), U3.44 (VREG_IN), U3.48 (USB_VDD), U3.49 (IOVDD)
/GPIO0: J3.4, U3.2 (GPIO0)
/GPIO1: J3.6, U3.3 (GPIO1)
/GPIO2: J3.8, U3.4 (GPIO2)
/GPIO3: J3.10, U3.5 (GPIO3)
/GPIO4: J3.12, U3.6 (GPIO4)
/GPIO5: J3.14, U3.7 (GPIO5)
/GPIO6: J3.16, U3.8 (GPIO6)
/GPIO7: J3.18, U3.9 (GPIO7)
/GPIO8: J3.20, U3.11 (GPIO8)
/GPIO9: J3.22, U3.12 (GPIO9)
/GPIO10: J3.24, U3.13 (GPIO10)
/GPIO11: J3.26, U3.14 (GPIO11)
/GPIO12: J3.28, U3.15 (GPIO12)
/GPIO13: J3.30, U3.16 (GPIO13)
/GPIO14: J3.32, U3.17 (GPIO14)
/GPIO15: J3.34, U3.18 (GPIO15)
/GPIO16: J4.27, U3.27 (GPIO16)
/GPIO17: J4.25, U3.28 (GPIO17)
/GPIO18: J4.23, U3.29 (GPIO18)
/GPIO19: J4.21, U3.30 (GPIO19)
/GPIO20: J4.19, U3.31 (GPIO20)
/GPIO21: J4.17, U3.32 (GPIO21)
/GPIO22: J4.15, U3.34 (GPIO22)
/GPIO23: J4.13, U3.35 (GPIO23)
/GPIO24: J4.11, U3.36 (GPIO24)
/GPIO25: J4.9, U3.37 (GPIO25)
/GPIO26_ADC0: J4.7, U3.38 (GPIO26_ADC0)
/GPIO27_ADC1: J4.5, U3.39 (GPIO27_ADC1)
/GPIO28_ADC2: J4.3, U3.40 (GPIO28_ADC2)
/GPIO29_ADC3: J4.1, U3.41 (GPIO29_ADC3)
/QSPI_SCLK: U2.6 (CLK), U3.52 (QSPI_SCLK)
/QSPI_SD0: U2.5 (DI(IO0)), U3.53 (QSPI_SD0)
/QSPI_SD1: U2.2 (DO(IO1)), U3.55 (QSPI_SD1)
/QSPI_SD2: U2.3 (IO2), U3.54 (QSPI_SD2)
/QSPI_SD3: U2.7 (IO3), U3.51 (QSPI_SD3)
/QSPI_SS: R1.1, R2.2, U2.1 (~CS), U3.56 (QSPI_SS)
/RUN: J4.29, U3.26 (RUN)
/SWCLK: J4.33, U3.24 (SWCLK)
/SWD: J4.31, U3.25 (SWD)
/USB_D+: J1.3 (D+), R3.1
/USB_D-: J1.2 (D-), R4.1
/XIN: C2.1, U3.20 (XIN), Y1.1
/XOUT: R5.1, U3.21 (XOUT)
/~USB_BOOT: J2.1, R1.2
GND: C1.2, C2.2, C3.2, C4.2, C5.2, C6.2, C7.2, C8.2, C9.2, C10.2, C11.2, C12.2, C13.2, C14.2, C15.2, C16.2, C17.2, J1.5 (GND), J1.6 (Shield), J2.2, J3.1, J3.3, J3.5, J3.7, J3.9, J3.11, J3.13, J3.15, J3.17, J3.19, J3.21, J3.23, J3.25, J3.27, J3.29, J3.31, J3.33, J3.35, J3.36, J4.2, J4.4, J4.6, J4.8, J4.10, J4.12, J4.14, J4.16, J4.18, J4.20, J4.22, J4.24, J4.26, J4.28, J4.30, J4.32, J4.34, J4.35, J4.36, U1.1 (GND), U2.4 (GND), U3.19 (TESTEN), U3.57 (GND)
unnamed: C3.1, R5.2, Y1.2
unnamed: R3.2, U3.47 (USB_DP)
unnamed: R4.2, U3.46 (USB_DM)
VBUS: C1.1, J1.1 (VBUS), U1.3 (VI)

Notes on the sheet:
Make sure R3 and R4 are close to RP2040
Make sure C10 is close to pin 44 of RP2040
Make sure C8 is close to pin 45 of RP2040
IOs
Power
Crystal
Flash

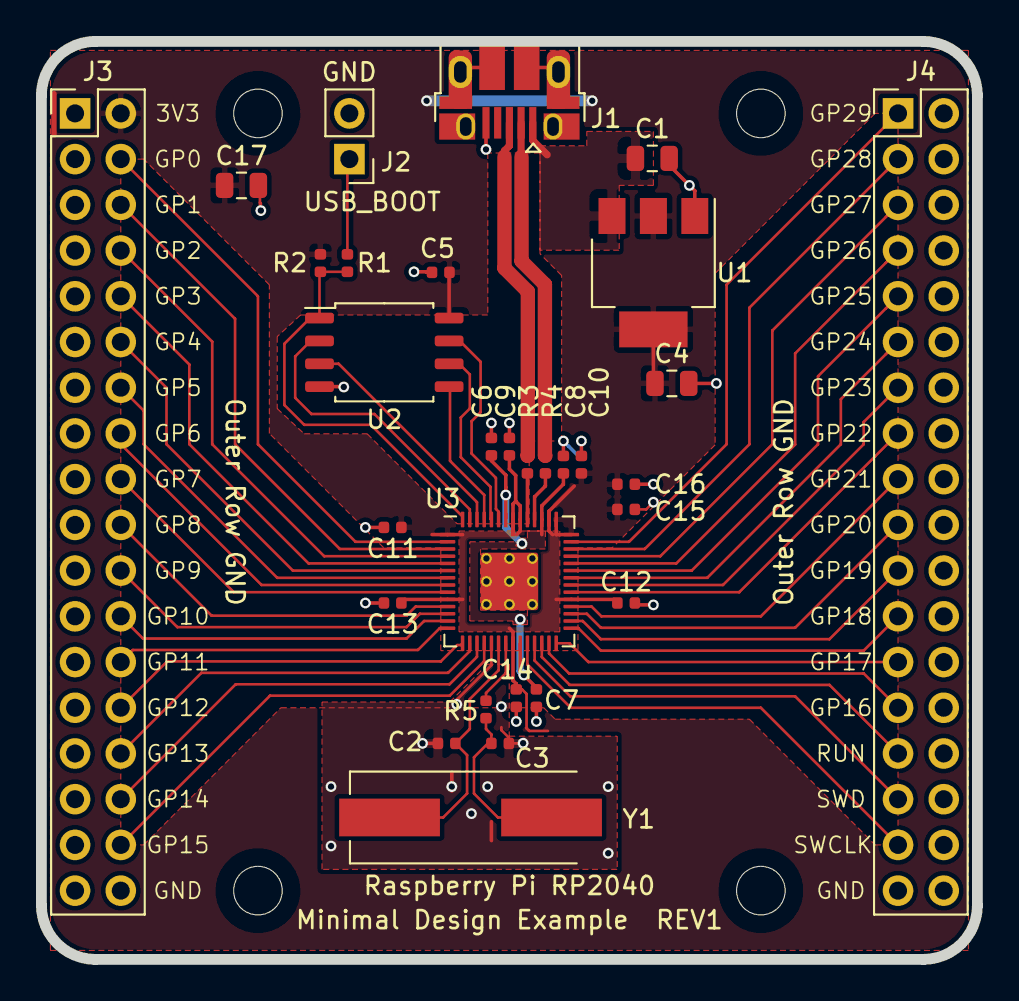
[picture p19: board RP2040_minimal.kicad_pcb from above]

Board: 2 copper layers, 52.0 x 51.0 mm, 34 parts (0 on the bottom side), 51 nets.

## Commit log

2022-03-01 Board Rev 1.1
    [RP2040GPSTracker-B_Cu.gbr, RP2040GPSTracker-B_Mask.gbr, RP2040GPSTracker-B_Paste.gbr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]
2022-03-01 Updated type in Board Files
    [RP2040GPSTracker-B_Cu.gbr, RP2040GPSTracker-B_Mask.gbr, RP2040GPSTracker-B_Paste.gbr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]
2022-03-03 Added 3D case
    [Case-CaseBottomPart.stl]
2022-03-04 Updated Case clearances and wall widths
    [Case-CaseBottomPart.stl]
2022-03-08 Updated USB trace differential routing
    [RP2040GPSTracker-B_Cu.gbr, RP2040GPSTracker-B_Mask.gbr, RP2040GPSTracker-B_Paste.gbr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]
2022-03-15 Board optimizations
    [RP2040GPSTracker-B_Cu.gbr, RP2040GPSTracker-B_Mask.gbr, RP2040GPSTracker-B_Paste.gbr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]
2022-03-16 Rev 1.2, Swapped out C13 Footprint for more suitable one
    [RP2040GPSTracker-B_Cu.gbr, RP2040GPSTracker-B_Mask.gbr, RP2040GPSTracker-B_Paste.gbr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]
2022-03-17 Added board schematic
2022-03-18 Rev 1.3. Implemented USB-C CC Channels. Fixed Z1 rotation. Expanded GPIO
    [RP2040GPSTracker-B_Cu.gbr, RP2040GPSTracker-B_Mask.gbr, RP2040GPSTracker-B_Paste.gbr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]
2022-03-26 Rev 2.0
    [CRYSTAL_ABMM2_ABR.step, DRL0008A.stp, DRY0006A.stp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]
2022-03-29 Rev 3.1 - Power-stage overhaul, SIM power finetuning
    [RP2040GPSTracker-B_Cu.gbr, RP2040GPSTracker-B_Mask.gbr, RP2040GPSTracker-B_Paste.gbr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]
2022-03-30 Revised case to accomodate new board layout
    [Bottom.step, Case-CaseBottomPart.stl]

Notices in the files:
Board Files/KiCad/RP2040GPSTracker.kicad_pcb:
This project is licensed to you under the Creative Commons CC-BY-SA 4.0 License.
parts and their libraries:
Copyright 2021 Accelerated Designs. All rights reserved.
